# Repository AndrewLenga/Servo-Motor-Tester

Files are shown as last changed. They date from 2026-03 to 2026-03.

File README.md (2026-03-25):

# Servo-Motor-Tester
This repository contains the full design suite—including Schematic, PCB Layout, and 3D CAD models—for a high-stability Servo Motor Tester. Engineered using a modified astable multivibrator topology, this device provides a robust hardware solution for validating RC servo response without the need for a microcontroller.
1. Executive Summary
Standard RC servos operate on a specific Pulse Width Modulation (PWM) protocol, requiring a carrier frequency (period) with a high-state duration.
This design leverages the NE555P precision timer to synthesize this waveform by decoupling the charge and discharge timing constants, ensuring high-fidelity signal reproduction for professional benchtop testing.
3. Circuit Architecture & Signal Integrity
A. Non-Symmetric Astable Topology
In a textbook 555 astable configuration, the duty cycle is constrained to achieve the duty cycle required for servo control, this design incorporates a signal diode in parallel with the discharge path.
Charging Phase: The timing capacitor charges through the series combination of the potentiometer 

Discharging Phase: 
It provides a low-impedance return path to Pin 7 (Discharge), effectively bypassing the primary timing resistors.

Implementation Specifications
Parameter	Specification
Logic Family	Bipolar NE555 / CMOS Equivalent
Input Voltage ( DC (Regulated)
Operating Frequency	
(Targeted for standard RC protocols)
Output Pulse Range  (Min) to  (Max)
Connector Interface	3-Pin Header (Signal-VCC-GND)
4. Documentation & Manufacturing
This project includes a comprehensive set of production files:
Schematic: Hierarchical design focusing on signal flow and net-clearance.


PCB Layout: Optimized for a compact footprint with enhanced ground planes for EMI reduction.


3D Model: STEP/STL files for mechanical integration and enclosure design.


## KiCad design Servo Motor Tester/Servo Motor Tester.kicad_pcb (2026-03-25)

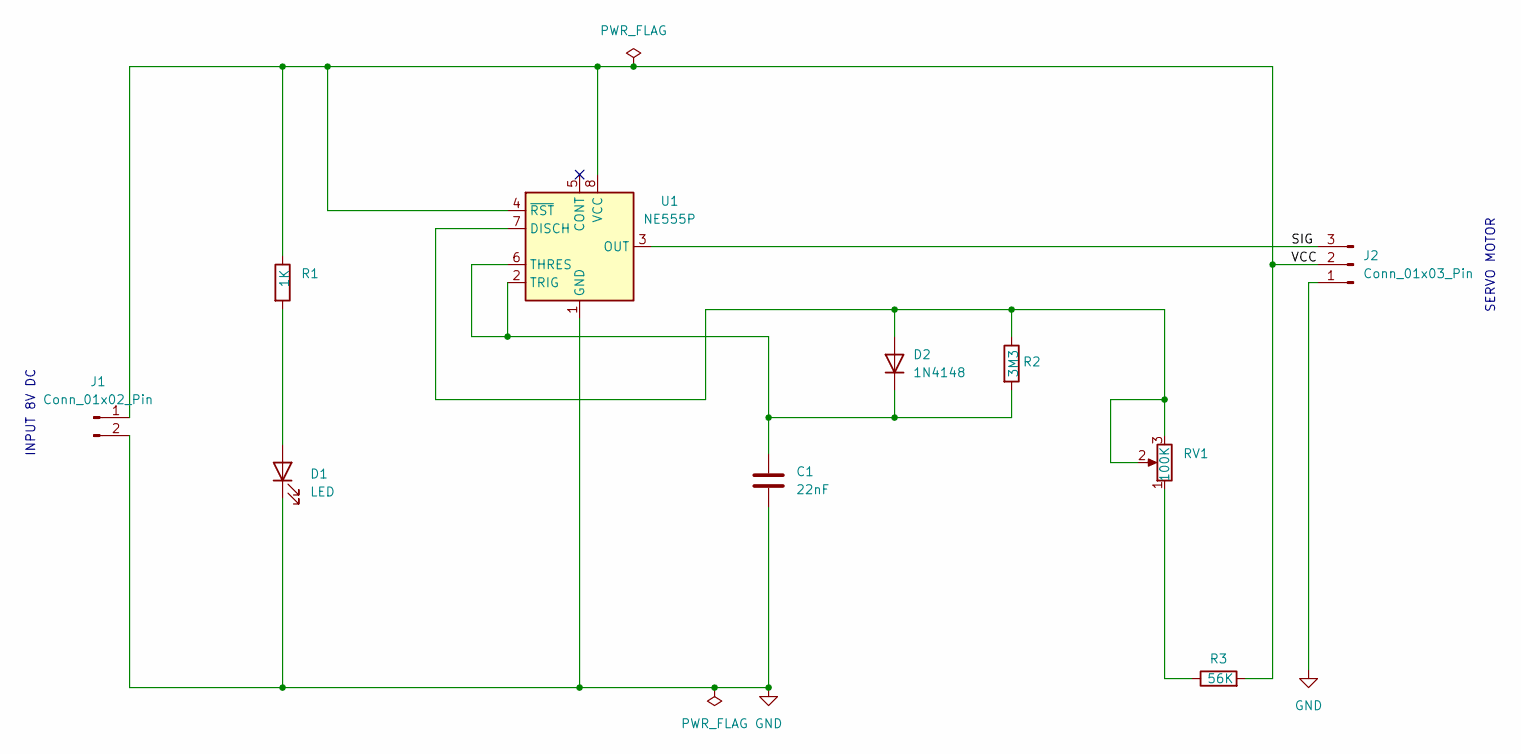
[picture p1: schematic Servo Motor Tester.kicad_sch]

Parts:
C1: 22nF; C_Disc_D4.3mm_W1.9mm_P5.00mm
D1: LED; LED_D3.0mm
D2: 1N4148; D_DO-35_SOD27_P7.62mm_Horizontal
J1: Conn_01x02_Pin; PinHeader_1x02_P2.54mm_Horizontal
J2: Conn_01x03_Pin; PinHeader_1x03_P2.54mm_Horizontal
R1: 1K; R_Axial_DIN0204_L3.6mm_D1.6mm_P7.62mm_Horizontal
R2: 3M3; R_Axial_DIN0207_L6.3mm_D2.5mm_P7.62mm_Horizontal
R3: 56K; R_Axial_DIN0207_L6.3mm_D2.5mm_P7.62mm_Horizontal
RV1: 100K; Potentiometer_Alps_RK163_Single_Horizontal
U1: NE555P; DIP-8_W7.62mm

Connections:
/SIG: J2.3, U1.3 (OUT)
/VCC: J1.1, J2.2, R1.1, R3.2, U1.4 (~RST), U1.8 (VCC)
GND: C1.2, D1.1 (K), J1.2, J2.1, U1.1 (GND)
unnamed: D1.2 (A), R1.2
unnamed: D2.2 (A), R2.1, RV1.2, RV1.3, U1.7 (DISCH)
unnamed: C1.1, D2.1 (K), R2.2, U1.2 (TRIG), U1.6 (THRES)
unnamed: R3.1, RV1.1

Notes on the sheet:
SERVO MOTOR
INPUT 8V DC

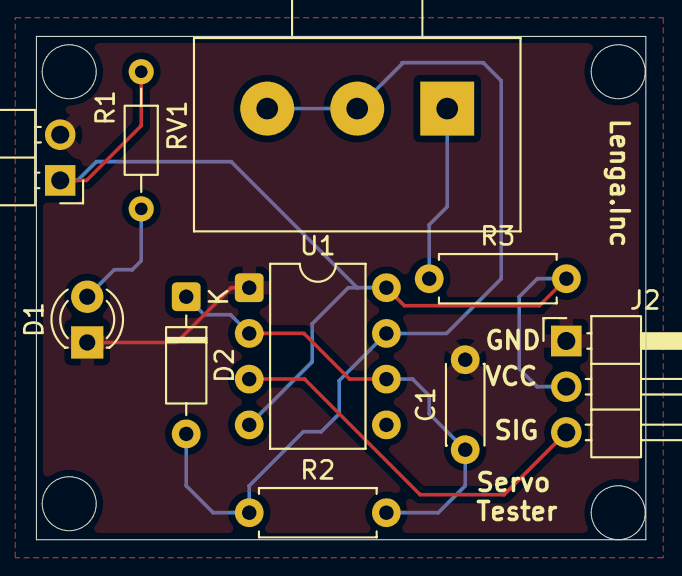
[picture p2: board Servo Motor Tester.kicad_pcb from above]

Board: 2 copper layers, 33.9 x 28.0 mm, 10 parts (0 on the bottom side), 7 nets.
